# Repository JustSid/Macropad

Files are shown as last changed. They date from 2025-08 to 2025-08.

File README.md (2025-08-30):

# Overview

A Raspberry Pi Pico based Macropad using components I had lying around. It supports arbitrary keymaps with multiple layers and a secondary mod layer. I made this to help with CAD/modelling applications, the goal was to cram as many possible keyboard shortcuts into a small space. The shell is 3D printed and the .step file is available in the CAD subdirectory.

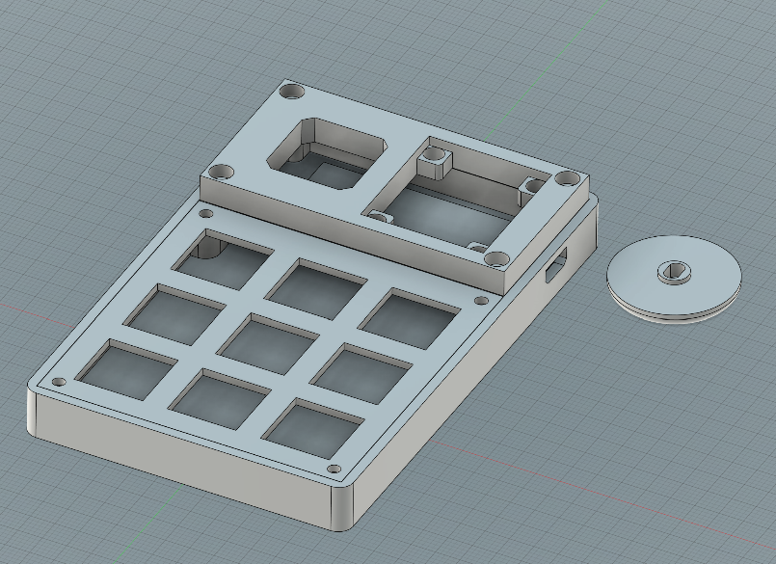
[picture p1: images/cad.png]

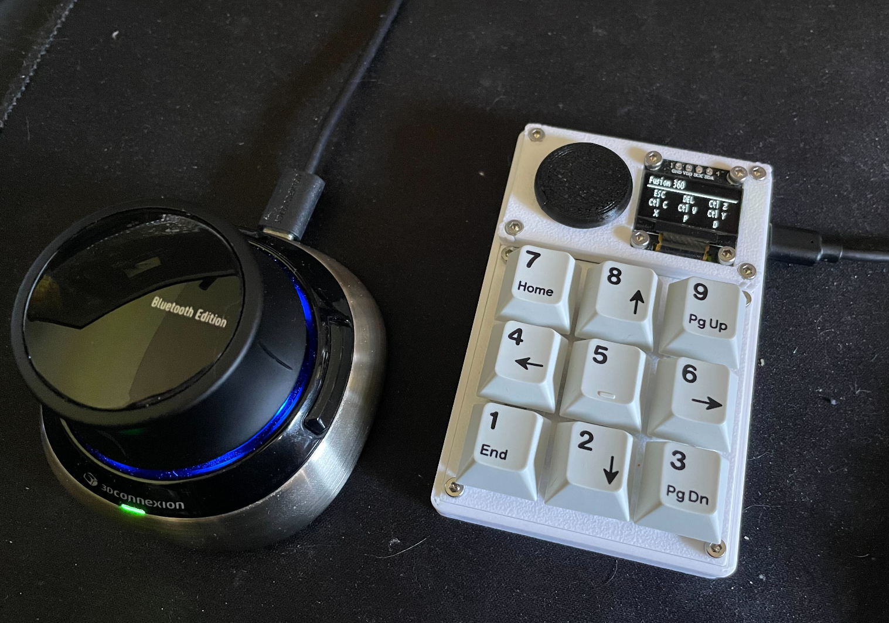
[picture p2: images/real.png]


# Building one

The whole project is pretty easy to put together assuming you have hands and a soldering iron. I don't expect anyone to actually build one, but there isn't a lot of sample code for something like this out there. It's either quote complex, targeted at fully custom keyboard builds, or one off MicroPython based. This to me is a happy medium using the Pico Pi SDK directly with enough complexity and configurability to be actually usable and maybe it'll be a good reference.

## Components

 - Raspberry Pi Pico (the first gen is ideal for this due to the very low performance requirement)
 - 9 cherry keys + keycaps
 - 12 M2.5x8 socket head bolts
 - 12 M2.5 heat set inserts
 - 4 M2x4 socket head bolts
 - 4 M2 heat set inserts
 - 6 1N4001 diodes
 - 1 SSD1306 display
 - 1 [Adafruit Thumbstick](https://www.adafruit.com/product/2765) + [breakout board](https://www.adafruit.com/product/3246)
 - Wires to tie it all together

The main component is a Raspberry Pi Pico or Pico 2, you can also use the W variant. The MCU will be mostly bored, so there is no need to waste a full Pico 2 on this. The other components were chosen based on "How many years have they been left unused in my drawer" and as such the project isn't necessarily based around parts availability.

## Assembly

The keys are held ins by friction only, a bit of CA glue may be desirable to retain them permanently so you can switch out the keycaps without ripping the keys out. The keys are soldered together as a key matrix with 3 rows and 3 columns with row 0 being top and column 0 being left. The display and thumbstick are both attached to the carrier piece on the top, although the thumbstick gets screwed in from the bottom and the display from the top. It's easier to desolder any pins from the display first and then soldering the wires straight to it so there is no interference with the Pico underneath.

Note that I'm stupid and didn't realize the keycaps would hang over the screws holding the key matrix in place. So screw it in first, then add the keycaps.

The pins can be configured via the config.h file, but the defaults are:

 - Key rows: GPIO 6, 7 and 8
 - Key columns: GPIO 5, 4 and 3
 - Display: SDA GPIO 16, SCL GPIO 17
 - Thumbstick: X axis GPIO 26, Y axis GPIO 27 (input and ground wired to the ADC pins)

## Compiling

Run CMake, specifying the Pico SDK path via the `PICO_SDK_PATH` environment variable and the board type via the `PICO_BOARD` CMake variable. Example:

```sh
PICO_SDK_PATH=foo cmake -DPICO_BOARD=pico2 -G Ninja -S "source dir" -B "binary dir"
```

# Configuration

The device is configured via a JSON file that can be accessed by navigating to the "System" keymap and hitting "Config". This will disable the HID keyboard and turn the device into a USB mass storage device with 64kb of storage with a "config.json" file in it. Once the configuration is on the device, ejecting the device will store it in the internal flash and reload the keymap configuration.

## Config syntax

The root object must be an array with each entry being one keymap. The keymaps are objects with the following keys:

 - `name`: The name of the keymap
 - `layers`: An array of layer objects

The layers array contains one or more key layer objects with the following keys:

 - `base`: The base layer that is displayed by default
 - `mod`: An optional mod array that is enabled when the mod key is pressed
 - `name`: An optional text object with the name of the layer

Each actual layer is an array of objects, one per key to be mapped (top left to bottom right):

 - `t`: The type of key, either `mod` or `hid` (defaults to `hid` if unspecified)
 - `v`: The value of the key (`hid` only, defaults to none), this is the same as defined in hid.h but without the `HID_KEY_` prefix
 - `m`: Modifiers to add to the key (`hid` only). Can be one of: `lctrl`, `rctrl`, `lshft`, `rshft`, `lalt` or `ralt`
 - `p`: Boolean to indicate if the key is a toggle or not (`mod` only, default `false`)
 - `l`: The label to display for the key (`hid` only)

## Example

Check out the examples folder for a full examples, but here is the high level overview

```json
[
  {
    "name": "Foo",
    "layers": [
      {
        "base": [
          {
            "t": "mod"
          },
          {
            "v": "X"
          }
        ],
        "mod": ...
      },
      ...
    ]
  },
  ...
]
```

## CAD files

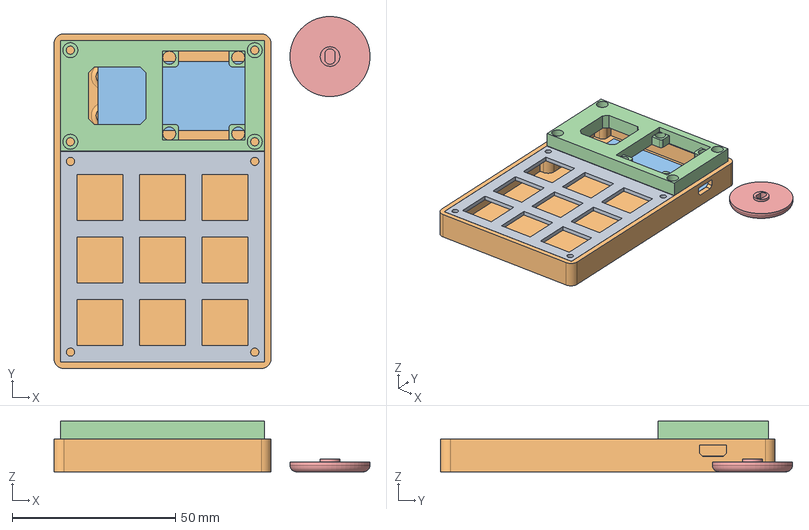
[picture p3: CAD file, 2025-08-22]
CAD/Macropad.step
96.6 x 107.7 x 15.5 mm
Keypad
Carrier
Nipple

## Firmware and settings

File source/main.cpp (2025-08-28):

//
// Created by Sidney on 03/07/2025.
//

#include <config.h>
#include <bsp/board_api.h>
#include "usb/usb_descriptor.h"
#include "logic/application.h"
#include "logic/flashfs.h"

static application app;

[[noreturn]] int main()
{
	board_init();

	flashfs_init();

	tud_init(BOARD_DEVICE_RHPORT_NUM);
	board_init_after_tusb();

	app.init();

	while(true)
	{
		app.update();
		sleep_ms(5);
	}
}

void tud_mount_cb()
{
	app.usb_state_changed();
}
void tud_umount_cb()
{
	app.usb_state_changed();
}

void tud_suspend_cb(bool remote_wakeup_en)
{
	app.usb_state_changed();
}
void tud_resume_cb()
{
	app.usb_state_changed();
}

void usb_ejected()
{
	flashfs_flush();
	app.usb_ejected();
}

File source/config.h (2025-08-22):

//
// Created by Sidney on 05/07/2025.
//

#ifndef CONFIG_H
#define CONFIG_H

#include <cstdint>
#include <iterator>

// Top to bottom
constexpr uint32_t keys_pins_rows[] = { 6, 7, 8 };
// Left to right
constexpr uint32_t keys_pins_cols[] = { 5, 4, 3 };

constexpr size_t num_key_rows = std::size(keys_pins_rows);
constexpr size_t num_key_cols = std::size(keys_pins_cols);

constexpr uint16_t display_width = 128;
constexpr uint16_t display_height = 32;

constexpr uint16_t display_left_third = display_width / 3;
constexpr uint16_t display_right_third = display_width - (display_width / 3);

constexpr uint16_t display_top_third = display_height / 3;
constexpr uint16_t display_bottom_third = display_height - (display_height / 3);

constexpr uint32_t i2c_pin_sda = 16;
constexpr uint32_t i2c_pin_scl = 17;

constexpr uint32_t analog_pin_x = 26;
constexpr uint32_t analog_pin_y = 27;

constexpr uint32_t font_height = 8;
constexpr uint32_t font_width = 5;

#endif //CONFIG_H

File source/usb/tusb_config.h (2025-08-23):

#ifndef _TUSB_CONFIG_H_
#define _TUSB_CONFIG_H_

// defined by board.mk
#ifndef CFG_TUSB_MCU
	#error CFG_TUSB_MCU must be defined
#endif

#ifndef CFG_TUSB_OS
	#error CFG_TUSB_OS must be defined
#endif

// RHPort number used for device can be defined by board.mk, default to port 0
#ifndef BOARD_DEVICE_RHPORT_NUM
	#define BOARD_DEVICE_RHPORT_NUM     0
#endif

#define BOARD_DEVICE_RHPORT_SPEED   OPT_MODE_FULL_SPEED

// Device mode with rhport and speed defined by board.mk
#if BOARD_DEVICE_RHPORT_NUM == 0
	#define CFG_TUSB_RHPORT0_MODE     (OPT_MODE_DEVICE | BOARD_DEVICE_RHPORT_SPEED)
#elif BOARD_DEVICE_RHPORT_NUM == 1
	#define CFG_TUSB_RHPORT1_MODE     (OPT_MODE_DEVICE | BOARD_DEVICE_RHPORT_SPEED)
#else
	#error "Incorrect RHPort configuration"
#endif

#ifndef CFG_TUSB_MEM_SECTION
#define CFG_TUSB_MEM_SECTION
#endif

#ifndef CFG_TUSB_MEM_ALIGN
#define CFG_TUSB_MEM_ALIGN          __attribute__ ((aligned(4)))
#endif

#define CFG_TUD_ENABLED       1

//--------------------------------------------------------------------
// DEVICE CONFIGURATION
//--------------------------------------------------------------------

#ifndef CFG_TUD_ENDPOINT0_SIZE
#define CFG_TUD_ENDPOINT0_SIZE    64
#endif

//------------- CLASS -------------//
#define CFG_TUD_HID               1
#define CFG_TUD_CDC               0
#define CFG_TUD_MSC               1
#define CFG_TUD_MIDI              0
#define CFG_TUD_VENDOR            0

// MSC Buffer size of Device Mass storage
#define CFG_TUD_MSC_EP_BUFSIZE    512

// HID buffer size Should be sufficient to hold ID (if any) + Data
#define CFG_TUD_HID_EP_BUFSIZE    16

#endif /* _TUSB_CONFIG_H_ */

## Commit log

2025-08-28 The config storage is no longer mounted by default but instead only when the Config mode is entered
    [application.cpp, main.cpp]
2025-08-29 Key layers can now also have names and two smaller fixes to align the readme and config file parser with each other
    [application.cpp]
